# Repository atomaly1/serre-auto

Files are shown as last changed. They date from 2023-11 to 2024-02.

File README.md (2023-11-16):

# serre-auto
Projet de serre automatisée avec approche LowTech

## Commandes Git
### Première configuration
* git config --global user.name username
* git config --global user.email user@email.com

### Ajouter les changements
* git add .
* git commit -m "my commit message"
* git push origin dev-branch

### Pour créer une nouvelle branche
* git branch branchname
* git checkout branchname

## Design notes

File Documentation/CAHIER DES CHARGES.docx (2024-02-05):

# CAHIER DES CHARGES

PROJET 4 : INNOVATION ET RECHERCHE

THEME LOWTECH : SERRE AUTOMATISEE A LA FERME DES OURS DE BOOFZHEIM

Groupe projet

Mike AGNES | mike.agnes@insa-strasbourg.fr
Alban LOPEZ | alban.lopez@insa-strasbourg.fr
Lucie WABARTHA | lucie.wabartha@insa-strasbourg.fr

Tuteur

Marc VEDRINES | marc.vedrines@insa-strasbourg.fr

Client

Brice GAENG | fermedesours@gmail.com

# Révisions

Numéro | Commentaire - Modifications | Date
001 | Rédaction initiale | 11/10/2023
002 | Ajout du système de ventilation, encombrement dans la serre, symétrie des ouvrants latéraux, doublement des capteurs dans la serre | 12/10/2023
003 | Changement des températures limites des pièces | 12/10/2023

# 1 Exigences non-fonctionnelles

## 1.1 Exigences liées à la sécurité et à l’environnement de travail

### 1.1.1 Directives applicables

L’installation doit être conforme à la directive “machines” 2006/42/CE et aux autres directives applicables (Directive Basse Tension, ATEX, MID, PED...). Aucun élément dangereux en mouvement ne doit être accessible.

Le dossier technique doit comprendre les éléments suivants :

- Une description générale du système,
- Le plan d’ensemble de la machine, les plans des circuits de commande, ainsi que les descriptions et explications pertinentes nécessaires à la compréhension du fonctionnement de la machine,
- Les plans détaillé et complets, accompagnés des notes de calcul, résultats d’essais, attestations, etc.
- Les normes et autres spécifications techniques utilisées, en précisant les exigences essentielles de santé et de sécurité couvertes par ces normes,
- Une copie de la notice d’instructions du système ;

### 1.1.2 Sécurité

La sécurité de l’ensemble de l’installation doit être testée en validant les organes de sécurité (bouton d’arrêt d’urgence, barrière immatérielle, autre système mécanique, protection contre les rayonnements électromagnétiques ou laser, respect des exigences de sécurité intrinsèques Ex, pas de poussière ou corps inhalable).

### 1.1.3 Bruits

Le bruit environnant l’installation doit être inférieur ou égal à 70 dB. La documentation liée à la mesure des bruits émis par l’installation doit être fournie.

### 1.1.4 Environnement

Pensez à favoriser les fournisseurs locaux et les éléments recyclés pour le choix des matériaux lorsque cela est possible.

Anticipez l’élimination de l’équipement en fin de vie.

En cas d’émanation de gaz COV (Composé Organique Volatile) ou fumée une installation d’aspiration à la source doit être mise en place avec filtre.

### 1.1.5 Vibrations

Les niveaux de vibrations de l’installation ne doivent pas dépasser :

- 2,5 m/s ² pour les vibrations transmises aux mains et aux bras
- 0,5 m/s² pour les vibrations transmises à l’ensemble du corps

### 1.1.6 Charges

Si l’utilisation de l’installation nécessite la manipulation d’une charge, celle-ci doit être inférieur ou égale à 15 kg en translation et 10 kg en portage.

L’installation doit répondre aux exigences de la Norme NF X35-109 relative à l’Ergonomie - Manutention manuelle de charge pour soulever, déplacer et pousser/tirer - Méthodologie d’analyse et valeurs seuils.

### 1.1.7 Ergonomie

L’installation doit respecter le poids, la hauteur et la distance pour le stockage du matériel et pour le déplacement de charges mobiles (chariot...) selon les exigences de la Norme NX X35-109 relative à l’Ergonomie - Manutention manuelle de charge pour soulever, déplacer et pousser/tirer - Méthodologie d’analyse et valeurs seuils.

L’installation doit prendre en compte la diversité des tailles des collaborateurs conformément aux exigences de la Norme NF EN ISO 14738 relative aux Prescriptions anthropométriques relatives à la conception des postes de travail sur les machines.

L’installation doit respecter les limites de la force humaine pour son utilisation (presse, manivelle) en répondant aux exigences de la Norme NF EN 1005-3+A1 relative aux Limites des forces recommandées pour l’utilisation de machines.

### 1.1.8 Accessibilité

La réflexion sur l’équipement doit tenir compte de l’accessibilité et de la signalisation pour l’anticipation de la diversité des handicaps (vue, audition, sens cognitif, handicaps physiques ou autres).

## 1.2 Exigences liées aux produits chimiques utilisés pour le fonctionnement de l’installation

Les agents classés toxiques pour la reproduction de catégorie 1 ou 2 sont à proscrire :

- Benzène
- Dérivés suivants des hydrocarbures aromatiques
  - Dérivés suivants des hydrocarbures aromatiques
  - Dinitrophénol
  - Aniline et homologues, benzidine et homologues, naphtylamines et homologues

## 1.3 Exigences techniques standards

### 1.3.1 Protection ESD

L’installation doit être conforme aux exigences ESD (décharges électrostatiques). Les surfaces de travail non-métalliques doivent être conformes aux exigences antistatiques. Les pièces métalliques doivent être reliées à la terre.

### 1.3.2 Température des pièces

Les éléments externes de l’installation qui peuvent dépasser les 40°C doivent être identifiables. Les pièces de plus de 70°C devront impérativement être protégées par un dispositif adéquat.

### 1.3.3 Nettoyage

Les pièces qui nécessitent un nettoyage ne doivent pas dépasser les dimensions suivantes :
L x P x H : 750 x 600 x 600 mm

Ces pièces pourront être démontées rapidement et facilement sans outillage spécifique.

### 1.3.4 Mise en route de l’installation

L’installation doit pouvoir être opérationnelle 20 minutes maximum après la mise sous tension.

### 1.3.5 Dispositif d’urgence

L’installation doit comporter un dispositif d’arrêt d’urgence clairement identifié permettant d’arrêter immédiatement l’installation et de la mettre en sécurité en bloquant tous les éléments mobiles de l’installation. Le dispositif doit être accessible et à proximité de l’utilisateur, dans la zone de travail.

Le réarmement du bouton d’arrêt d’urgence ne doit pas provoquer un redémarrage de l’installation. Cependant l’installation doit pouvoir être redémarrée aisément sans une procédure spécifique de remise en état de marche.

### 1.3.6 Dispositifs de régulation

Un indicateur (affichage) de bon fonctionnement pour chaque dispositif de régulation doit être visible par l’utilisateur. Les valeurs seuils de ces indicateurs doivent être clairement affichées :

Vert = Dans la tolérance
Rouge = Hors tolérance supérieure
Jaune = Hors tolérance inférieure

### 1.3.7 Alimentation électrique

L’installation doit être optimisée énergétiquement. L’aspect énergétique sera l’un des critères majeurs de sélection des fournisseurs.

Si possible, un mode “économie d’énergie” ou une mise hors tension devra être prévu pour réduire l’impact énergétique de l’équipement lorsque celui-ci n’est pas en fonctionnement.

Pour chaque type d’énergie nécessaire au fonctionnement de l’installation, les valeurs suivantes doivent être communiquées :

- Consommation en veille en kWh
- Consommation nominale en kWh
- Consommation moyenne journalière en kWh

Tension de raccordement : Monophasé 230 VAC 50Hz

Régime de neutre : TT

### 1.3.8 Encombrement

Les dimensions maximales de l’installation ne doivent pas dépasser les dimensions suivantes :

- Largeur ou Longueur : 3 m
- Hauteur : 3 m

Dans les serres, en-dehors des parois, aucun équipement et aucun câble ne doit être positionné à moins de 2m de hauteur.

### 1.3.9 Poids

Le poids maximal de l’installation ne doit pas dépasser 2,5 T/m².

### 1.3.10 Disponibilité

L’installation doit être disponible 16h par jour (6h-22h). Une maintenance longue annuelle planifiée ne dépassant pas 3 jours maximum est tolérée.

La non-disponibilité journalière, en raison d’une intervention humaine pour maintenance préventive ou ajustage, ne doit pas dépasser 5% du temps d’utilisation.

### 1.3.11 Longévité

La conception de l’installation doit être prévue pour une durée de vie minimale de 10 ans.

## 1.4 Exigences liées à l’informatique et à la cybersécurité

### 1.4.1 Topologie réseau

L’installation doit pouvoir être connectée au réseau informatique via une prise Ethernet standardisée IEEE 802.3.

### 1.4.2 Système d’exploitation

Les systèmes d’exploitation Windows et Linux sont préconisés.

### 1.4.3 Applications

Les applications installées doivent être à jour de leur version la plus récente à la date de réception.

Si les applications sont concernées par les domaines ci-dessous elles doivent répondre aux prérequis indiqués.

A. Authentification
- Toute ressource qui n’est pas public doit faire l’objet d’un système d’authentification adapté au degré de confidentialité.
- La gestion des mots de passe dans l’interface utilisateurs ne doit pas permettre d’être visible d’un tiers ou de permettre l’auto-complétions.
- Les fenêtres d’authentification ne doivent être disponibles qu’en version crypté (url : https)
- Ne jamais fournir l’élément faux dans une connexion utilisateur / mot de passe erronée
- Si des mots de passe sont envoyé par mail non-crypté, ils doivent avoir une durée de validité limitée
- Ne jamais utiliser des mots de passe par défaut à la création d’un compte
- Les mots de passe ne doivent jamais transiter dans l’url en tant que paramètre
- Ne pas utiliser de système de récupération de mot de passe par question secrète
- Les mots de passe doivent respecter à minima les points suivants :
  - 12 caractères
  - Contenir chiffres
  - Contenir des lettres majuscules
  - Contenir des lettres minuscules
  - Contenir des caractères spéciaux
- Mettre en place des systèmes contre le “bruteforce” et l’attaques au dictionnaire lorsqu’il y a une fenêtre utilisateur / mot de passe
- Les informations de connexion ne devraient jamais être transmises ou stockées en clair
- Rediriger toutes les connexions http vers du https
- Toutes les connexions infructueuses doivent être logger
- Afficher la date de dernière connexion ainsi que le nombre d’erreur d’authentification commise
- Désactiver les comptes après plusieurs connexions infructueuses, attention tout de même aux DDOS
B. Gestion de session
- Les sessions doivent être révoquées après une période de temps
- Le serveur doit révoquer le session ID à la déconnexion
- Le stockage de la session doit se faire de manière sécurisée si elle contient des informations sensibles
- L’utilisateur doit avoir la possibilité de révoquer sa session manuellement
C. Autorisations
- Un contrôle d’autorisation doit être effectué si les ressources sont non-public et doit se faire du coté serveur et non du coté client
- Les utilisateurs ne doivent avoir que les droits nécessaires à leur besoin
- Mettre en place une page d’accès refusé pour les utilisateurs n’ayant pas de droits
D. Contrôle des saisies
- Toutes informations reçues par l’application doivent être vérifiées afin de garantir l’intégrité et la sécurité et ce du coté serveur
E. Encodage des données de contexte
- Tous les fichiers et données doivent fournir un encodage explicit, soit par le nom du fichier (css, js, etc.) soit par des mécaniques dans le code (Content-Type : text/html; charset=utf8, etc.).
F. Côté client
- Ne pas transmettre d’information confidentiel (mot de passe) du coté client
- Garantir la transmission sécurisée des données si nécessaire
G. Gestion de erreurs / Logs
- Ne pas mettre d’information confidentielle dans les messages d’erreurs

Le code source de l’application devra être fourni et documenté.

### 1.4.4 Ports USB

L’exécution automatique (Autorun) doit être désactivé sur tous les ports USB.

### 1.4.5 Antivirus

Le système doit être équipé d’un antivirus à jour.

### 1.4.6 Sauvegardes

Un système de sauvegarde des systèmes d’exploitation doit être fourni avec la solution.

## 1.5 Exigences liées à la documentation

L’installation doit être livrée avec une documentation complète, incluant, le manuel d’utilisation et la documentation technique.

Les inscriptions visibles sur l’installation et utilisables par les utilisateurs doivent être obligatoirement en français.

Liste des documents à fournir au plus tard pour la réception technique (ou pré-réception le cas échéant). Les documents devront idéalement être sous format informatique et les plans devront pouvoir être en version modifiable pour une éventuelle modification ultérieure.

Exigences concernées | Documents | Langue | Nombre exemplaires papier
Directive machine 2006/42/CE | Documentation technique de l’installation | Français | 1
Documentation | Manuel d’utilisation de l’installation | Français | 1
Documentation | Liste de tous les sous-traitants et fournisseurs pour chaque pièce et sous-ensemble | Français | 1
Maintenance | Liste des pièces critiques à mettre en stock | Français | 1
Maintenance | Liste des pièces d’usure | Français | 1
Maintenance | Manuel de maintenance préventive | Français | 1
Maintenance | Manuel de maintenance curative | Français | 1
Maintenance | Plan de maintenance standard pour l’utilisation spécifiée dans le cahier des charges | Français | 1
Informatique | Documentation du logiciel et code source des microcontrôleurs programmables | Français | 1

## 1.6 Exigences liées à la Maintenance

Une liste de toutes les pièces de rechange de l’équipement doit être fournie en spécifiant celles qui sont des pièces d’usure.

Une pièce d’usure est définie par les critères suivants :

- Mean Time Between Failure (MTBF) : < 30 000 heures

Une documentation technique complète de l’installation doit être fournie comprenant à minima les schémas électriques, mécaniques, pneumatiques et hydrauliques ainsi qu’un manuel de maintenance.

Un plan de maintenance préventive standard pour l’utilisation spécifiée doit être fourni (il peut être intégré au manuel de maintenance).

## 1.7 Confidentialité

Le fournisseur s’engage à mettre à disposition du grand public l’ensemble de la documentation de l’installation. Ceci a pour but d’encourager la reproduction et l’amélioration du système développé.

## 1.8 Transport et livraison

L’installation devra être livrée à l’adresse suivante :

Ferme des Ours
rue de Strasbourg
67860 Boofzheim (France)

Le transport de la marchandise jusqu’à l’adresse de livraison, l’installation de l’équipement à son emplacement définitif et sa mise en service sont sous la responsabilité du fournisseur.

## 1.9 Formation

La formation des utilisateurs experts est sous la responsabilité du fournisseur.

La formation des utilisateurs devra aborder les thèmes suivants (liste non-exhaustive) :

- Connaissances techniques matériel/logiciel
- Contenu du manuel utilisateur
- Description des différents signaux (lumineux, sonore, etc.)
- Contenu des opérations de maintenance
- Formation minimum à l’utilisation

# 1 Exigences fonctionnelles

## 1.1 Présentation générale

### 1.1.1 Fondement du projet

Ce projet s’inscrit dans le cursus d’étude d’ingénieur en mécatronique par alternance de l’INSA Strasbourg et plus spécifiquement dans le module Projet 4 : Recherche et Innovation. La thématique générale abordée est la LowTech avec comme axe pratique l’automatisation d’une serre maraîchère.

Le projet est réalisé conjointement par trois étudiants de l’INSA, un professeur référent ainsi qu’un maraîcher de la région Strasbourgeoise.

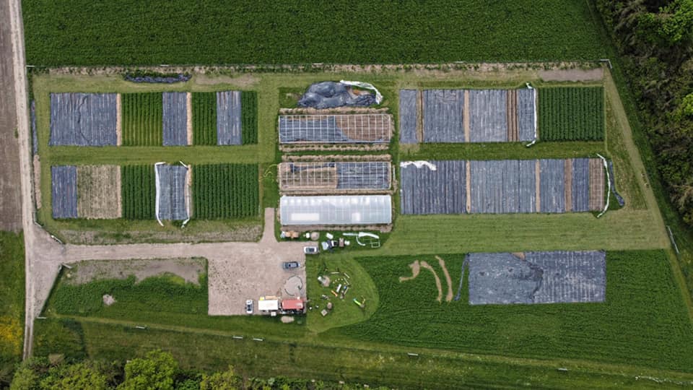
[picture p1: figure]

Figure 1: Vue aérienne de la Ferme des Ours à Boofzheim (67)

L’objectif principal est de réaliser une régulation de la température et de l’humidité d’une serre, par l’automatisation des ouvrants latéraux.

### 1.1.2 Attentes du projet

A. Procédé

Motorisation et automatisation des ouvrants d'une serre ainsi qu'automatisation d'un ventilateur. Le but est de réguler la température intérieure, l'humidité et de protéger la serre en cas d'orages. Le système doit intégrer des capteurs de températures, d'humidité et de niveau de vent. Il doit être possible pour l'utilisateur de définir ses propres seuils, et de passer en mode manuel en cas de besoin. L'utilisateur doit pouvoir visualiser les caractéristiques des capteurs et accéder à l'historique des données.

B. Documentation

Le projet est réalisé en accord avec les valeurs de libre échange des informations et des données. Toutes les informations nécessaires à la reproduction et à la modification du système seront mises à disposition du grand public.

### 1.1.3 Planification

La planification du projet s’oriente en quatre phases principales. Ces phases sont détaillées dans le tableau ci-dessous.

Tableau 1 : Planification du projet de serre automatisée

| Phases | Planifié pour
1 | Rédactions de veilles technologiques | 13/10/23
| Analyse de l'existant | 13/10/23
| Rédaction cahier des charges | 13/10/23
2 | Choix des solutions électronique | 15/11/23
| Choix des solutions mécanique | 15/11/23
| Ecriture du programme | 15/11/23
3 | Mise en place d'une liste de tests | 16/12/23
4 | Création de la documentation, rapport et support de présentation | 11/01/24

## 1.2 Description de l’état actuel

### 1.2.1 Topographie

Le terrain dispose d’une superficie totale de 0,89 hectare. Il est situé à l'abord de la rue de Strasbourg à l’entrée du village de Boofzheim (67860).

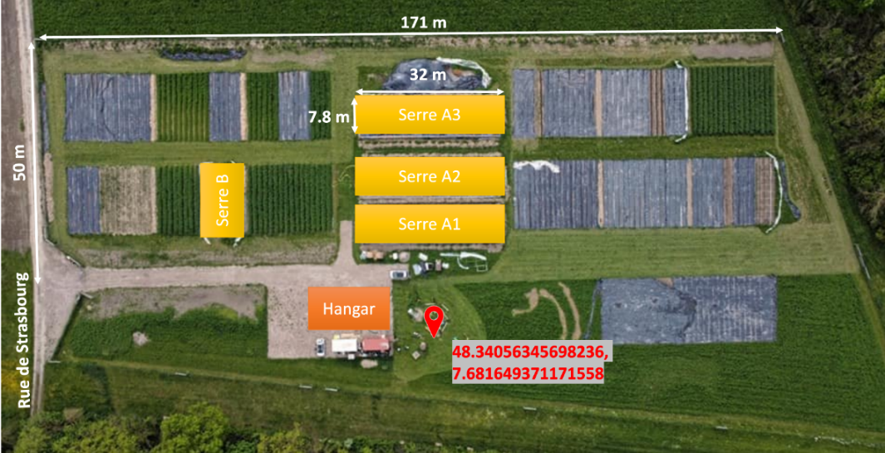
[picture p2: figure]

Figure 2 : Topographie du site de la Ferme des Ours

La serre est un produit standard “TUNNEL Pro 7.80M SC” fournie par Serresvaldeloire dont le plan est illustré ci-dessous.

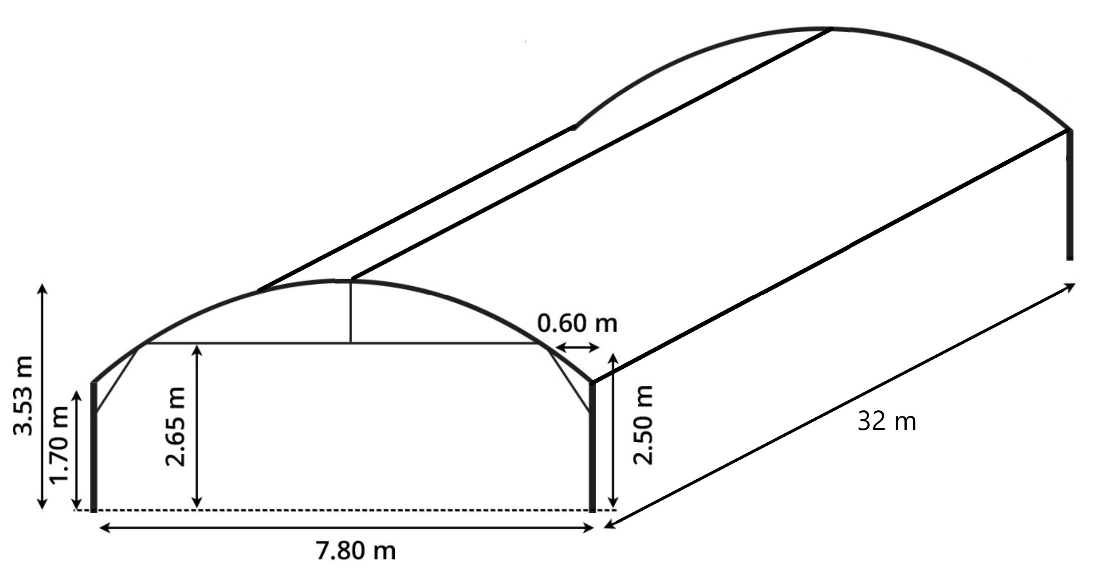
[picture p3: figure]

Figure 3 : Dimensions de la serre TUNNEL Pro 7.80M SC

### 1.2.2 Système mécanique d’ouverture

Le système actuel permettant l’ouverture des ouvrants latéraux se compose d’une manivelle entraînant un réducteur. Un bras télescopique en rotation permet la transmission au tube provoquant l’enroulage ou le déroulage de la bâche couvrant les ouvrants.

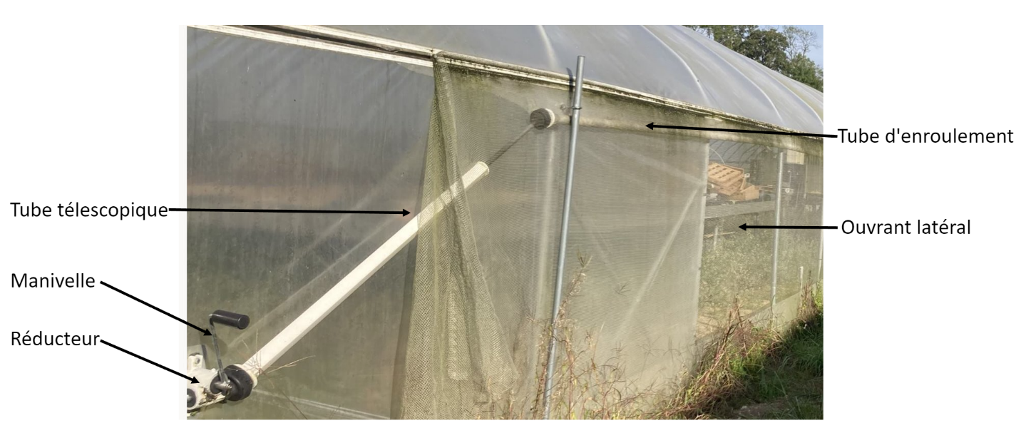
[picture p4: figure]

Figure 4 : Nomenclature du système d'ouverture latéral

### 1.2.3 Procédé

Lorsque l’utilisateur juge que la température ou l’humidité dans la serre est trop importante, il actionne, une après l’autre, les deux manivelles pour enrouler les bâches latérales.

Dans une logique similaire, lorsque l’utilisateur juge le temps défavorable, il actionne les manivelles de manière à descendre les bâches latérales.

### 1.2.4 Réseau

Le hangar dispose d’un routeur Wi-Fi 5 GHz / 2,4 GHz qui recouvre l’entièreté du terrain. Le réseau Wi-Fi n’est pas relié au réseau internet.

### 1.2.5 Alimentation

Le hangar dispose d’un coffret électrique relié au réseau EDF (230 VAC 50Hz). Chaque serre contient un coffret électrique déporté du coffret principal.

## 1.3 Description du procédé souhaité

### 1.3.1 Fonctions principales

A. Ouvrir et fermer automatiquement la serre en fonction des conditions fixées par l'utilisateur

Le système, en mode automatique, doit gérer la température et l’humidité interne de la serre, en actionnant automatiquement l’ouverture et la fermeture des ouvrants afin de ne pas dépasser les seuils renseignés par l’utilisateur. De plus, un système de ventilation peut être activé automatiquement.

Par ailleurs, le système doit automatiquement fermer les ouvrants en cas de vent trop violent afin de protéger la serre.

B. Permettre à l'utilisateur d'actionner la motorisation de l'ouverture et la fermeture de la serre

Lorsqu’il le souhaite, l’utilisateur doit pouvoir ouvrir et fermer les ouvrants par le biais d’une commande électrique physique prioritaire par rapport à l’asservissement.

C. Permettre à l'utilisateur d'effectuer manuellement l'ouverture et la fermeture de la serre

Lorsque le système n’est pas alimenté électriquement, l’utilisateur doit pouvoir actionner un système mécanique permettant d’ouvrir et de fermer les ouvrants latéraux de la serre.

D. Permettre à l’utilisateur d’actionner le système de ventilation

Lorsqu’il le souhaite, l’utilisateur doit pouvoir allumer et éteindre le système de ventilation par le biais d’une commande électrique physique prioritaire par rapport à l’asservissement.

### 1.3.2 Fonctions contraintes

A. Permettre une ouverture variable et symétrique des parois latérales

Le taux d’ouverture des parois latérales peut être situé entre une valeur maximale (serre complètement ouverte) et minimale (serre complètement fermée). Les deux ouvrants sont contrôlés par la même loi de commande et sont donc actionnés conjointement.

B. Informer l'utilisateur des paramètres de régulation via une interface numérique locale

Une interface permettant un affichage des données de la serre et des seuils doit être intégrée au système et consultable sur le réseau local de l’utilisateur.

C. Permettre à l'utilisateur de paramétrer les valeurs de seuils

Les seuils de tolérance des différentes données (température, humidité et intensité du vent) gérées par le système, doivent être paramétrables via une interface par l’utilisateur.

D. Permettre à l'utilisateur de visualiser l'historiques des données mesurées

Un suivi des données de température, d’humidité et d’intensité de vent doit être possible. Pour se faire, les données récoltées par les capteurs doivent être stockées et consultable par l’utilisateur.

E. Alimenter électriquement le système

Le système doit être alimenté électriquement par le biais de l’arrivée électrique du client (réseau EDF). Un coffret électrique est disposé dans chaque serre.

F. Exploiter uniquement de l'énergie électrique et mécanique

Seules les sources d’énergie déjà présentes sur site seront utilisées. Aucun autre système pneumatique, hydraulique ou thermique ne sera mis en place.

G. Résister aux conditions climatiques

Conditions limites à l’intérieur de la serre :

- Température : -10°C à 70°C
- Humidité (degré hygrométrique) : 10% à 100%
- Vitesse de vent : Faible

Conditions limites à l’extérieure de la serre :

- Température : -25°C à 50°C
- Humidité (degré hygrométrique) : 10% à 100%
- Vitesse de vent : Rafales pouvant aller jusqu’à 150 km/h
H. Utiliser du matériel et des technologies standardisés

Le système doit être constitué de composants facilement remplaçables et produit en grandes séries. Les technologies mises en œuvre doivent également être répandues et les ressources nécessaires à la formation à ces équipements doivent être disponibles en ligne et gratuitement.

I. Utiliser des logiciels libres

Privilégier l’utilisation de logiciels et systèmes d’exploitation libres (aussi connu sous l’appellation open source) et gratuits.

J. Réduire/optimiser la consommation énergétique du système

Les choix de composants, de stratégies à appliquer et de matériaux doivent être réalisés en tenant compte de la consommation énergétique générée, afin de réduire au mieux la dépense énergétique du système.

K. Garantir l’intégrité et la qualité des données

Si possible, les capteurs situés dans la serre devront être doublés afin de garantir l’intégrité et la qualité des valeurs mesurées.

# Annexe

## A. Documentation du réducteur

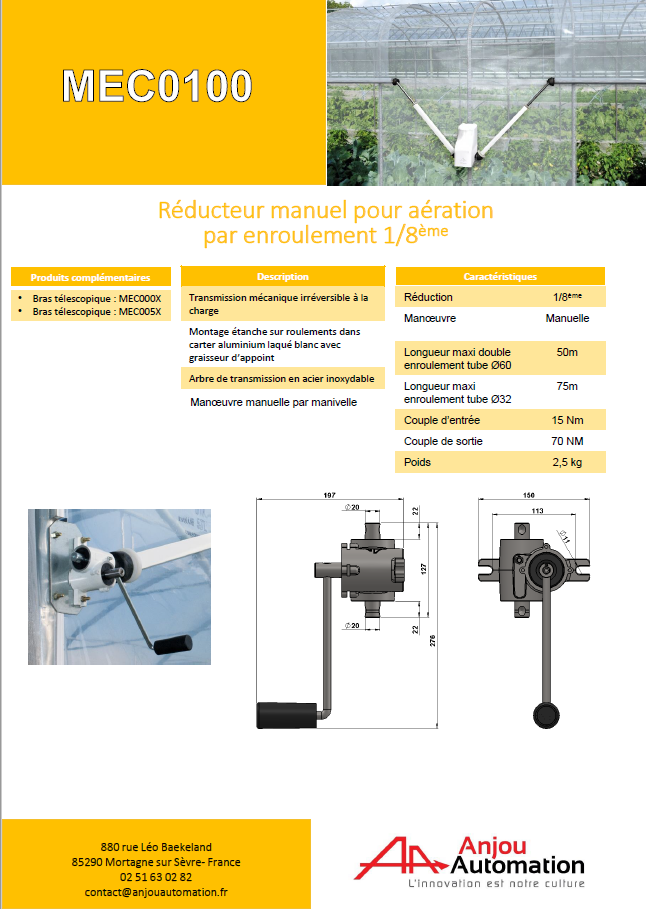
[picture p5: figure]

## B. Documentation du bras télescopique

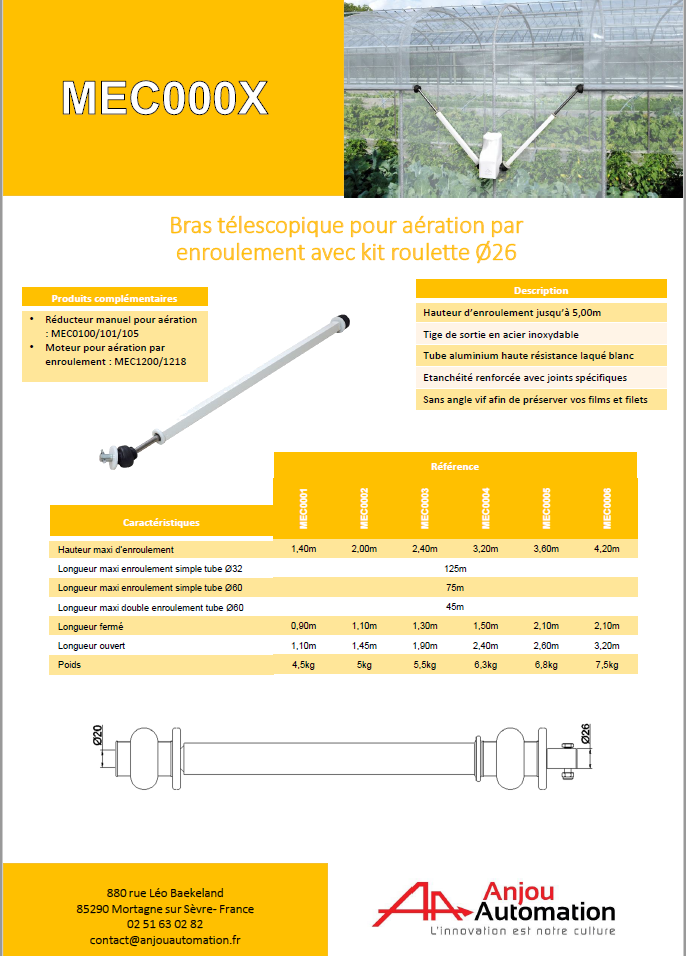
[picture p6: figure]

Département de Génie Mécanique & Mécatronique

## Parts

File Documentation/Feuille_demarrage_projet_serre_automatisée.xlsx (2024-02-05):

Feuille de Démarrage de projet
Nom du projet: |  | Serre Automatisée Lowtech : Ferme des Ours à Boofzheim
1 - VUE D'ENSEMBLE (Description de l'état actuel / Problème) |  |  |  |  |  |  | 2 - ATTENTES DU PROJET (Description de l'état souhaité) |  | 18
Etat actuel Ouverture/Fermeture de la serre à l'aide d'une manivelle. Absence de capteurs de température, de taux d'humidité et de vitesse de vent. Le client ouvre et ferme la serre à la main. Cela est fait en fonction de la météo qui parfois varie rapidement dans une journée. Problème Lorsque la serre est exposée au soleil, la température monte très rapidement. Si la serre n'est pas ouverte, l'ensemble des cultures peuvent être perdues en quelques heures. Cela représente une perte de temps et de qualité de vie pour le maraîcher. Il y a également un risque de dégradation de la serre en cas d'orage ou de vents forts. |  |  |  |  |  |  | Process Motorisation et automatisation des ouvrants d'une serre ansi que automatisation d'un ventilateur. Le but est de réguler la température intérieure, l'humidité et de protéger la serre en cas d'orages. Le système doit intégrer des capteurs de températures, d'humidité et de niveau de vent. Il doit être possible pour l'utilisateur de définir ses propres seuils, et de passer en mode manuel en cas de besoin. L'utilisateur doit pouvoir visualiser les caractéristiques des capteurs et accéder à l'historique des données.
 |  |  |  |  |  |  | Limites du projet
 |  |  |  |  |  |  | Non abordé dans ce projet Le projet s'arrête aux ouvertures latérales de la serre, ainsi que, si le temps le permet, de l'automatisation d'un système de ventilation. L'irrigation de la serre, l'ensoleillement, le taux de CO2 ainsi que l'orientation du vent ne seront notamment pas étudiés.
 |  |  |  |  |  |  | Livrables du projet (hors produit)
 |  |  |  |  |  |  | Une documentation claire expliquant le fonctionnement du système et comment le modifier/réparer (schémas éléctriques et mécaniques, programmes commentés, instructions...).
5 - PLANNING |  |  |  |  |  |  | 6 - EQUIPE
 | Phases |  |  | Planifié pour |  | Réalisé | Nom | Fonction
1 | Rédactions de veilles techno (meca/électronique) |  |  | 13/10/23 |  |  | AGNES Mike | Apprenti Ingénieur mécatronicien
 | Analyse de l'existant |  |  | 13/10/23 |  |  | LOPEZ Alban | Apprenti Ingénieur mécatronicien
 | Rédaction cahier des charges |  |  | 13/10/23 |  |  | WABARTHA Lucie | Apprentie Ingénieure mécatronicienne
2 | Choix des solutions (électronique) |  |  | 15/11/23 |  |  | VEDRINES Marc | Tuteur de projet - Professeur mécanique
 | Choix des solutions (mécanique) |  |  | 15/11/23 |  |  | GAENG Brice | Client - Maraîcher
 | Ecriture du programme |  |  | 15/11/23
3 | Mise en place d'une liste de tests |  |  | 16/12/23
4 | Création de la documentation, rapport et support de présentation |  |  | 11/01/24
Projet validé par (Date, Signature)
Tuteur du projet |  |  | Equipe projet |  | Client

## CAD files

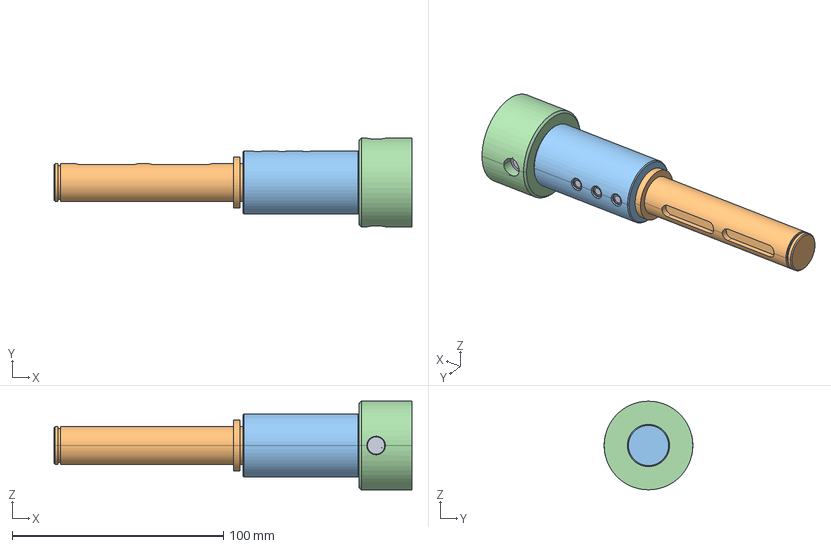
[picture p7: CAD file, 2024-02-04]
Documentation/CAO/Accouplement moteur - bras télescopique/STEP/a1-accouplement_moteur_1_asm.stp
169.5 x 42.0 x 42.0 mm
100-TECHNOI_425001_ARBRE_SORTIE
10-ACCOUPLEMENT
200-ANJOU_MEC0002_BRAS_TELESCOP
300-BOSSARD_BN617_VIS_M6X8 x 3
310-BOSSARD_BN617_VIS_M10X12 x 2

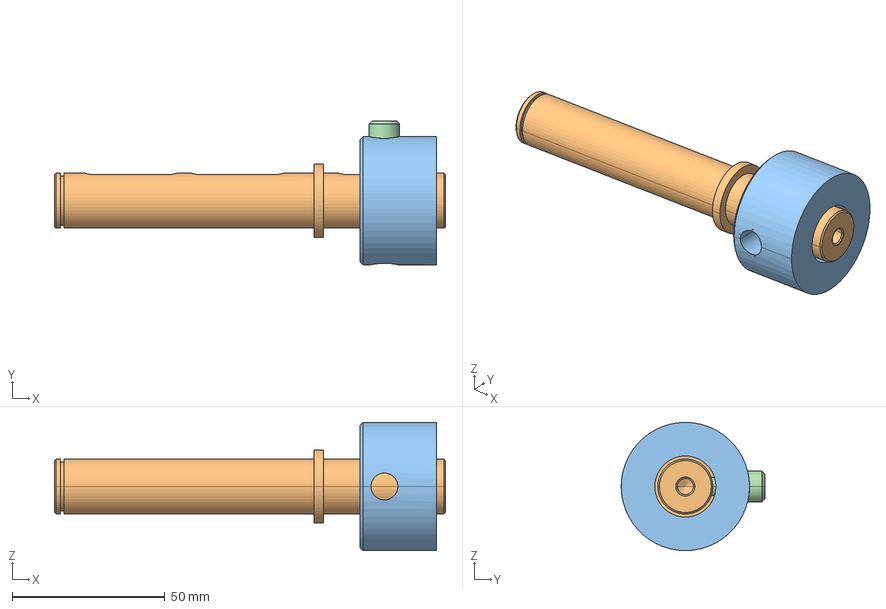
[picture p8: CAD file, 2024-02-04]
Documentation/CAO/Accouplement moteur - bras télescopique/STEP/a2-accouplement_moteur_2_asm.stp
128.0 x 47.0 x 42.0 mm
100-TECHNOI_425001_ARBRE_SORTIE
200-ANJOU_MEC0002_BRAS_TELESCOP
320-BOSSARD_BN619_VIS_M10X20_L

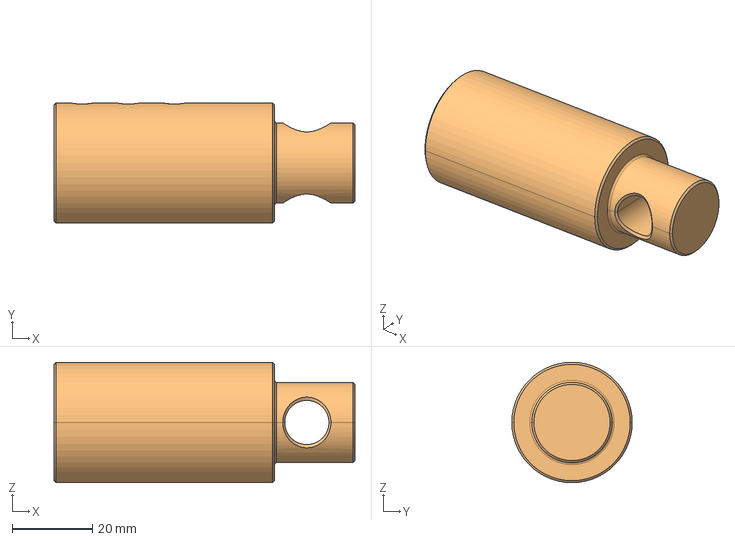
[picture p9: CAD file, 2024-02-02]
Documentation/CAO/accouplement.stp
75.0 x 30.0 x 30.0 mm

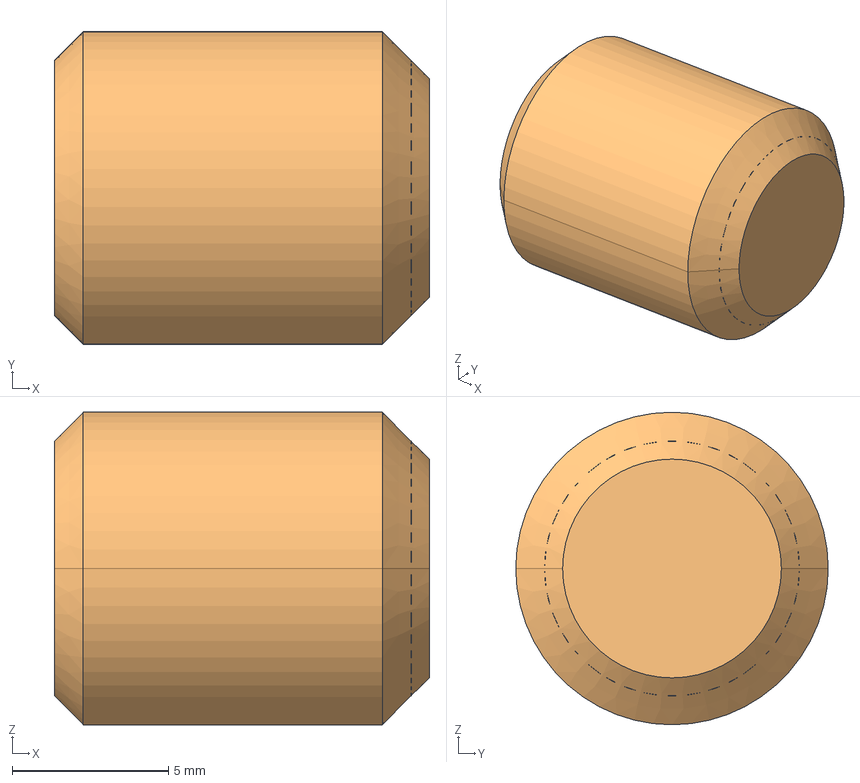
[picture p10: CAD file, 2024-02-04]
Documentation/CAO/Accouplement moteur - bras télescopique/STEP/310-bossard_bn617_vis_m10x12.stp
12.0 x 10.0 x 10.0 mm

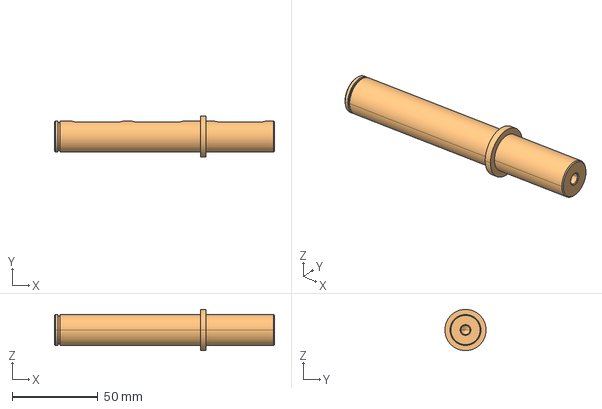
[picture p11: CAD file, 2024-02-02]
Documentation/CAO/arbre_reducteur.stp
128.0 x 24.0 x 24.0 mm

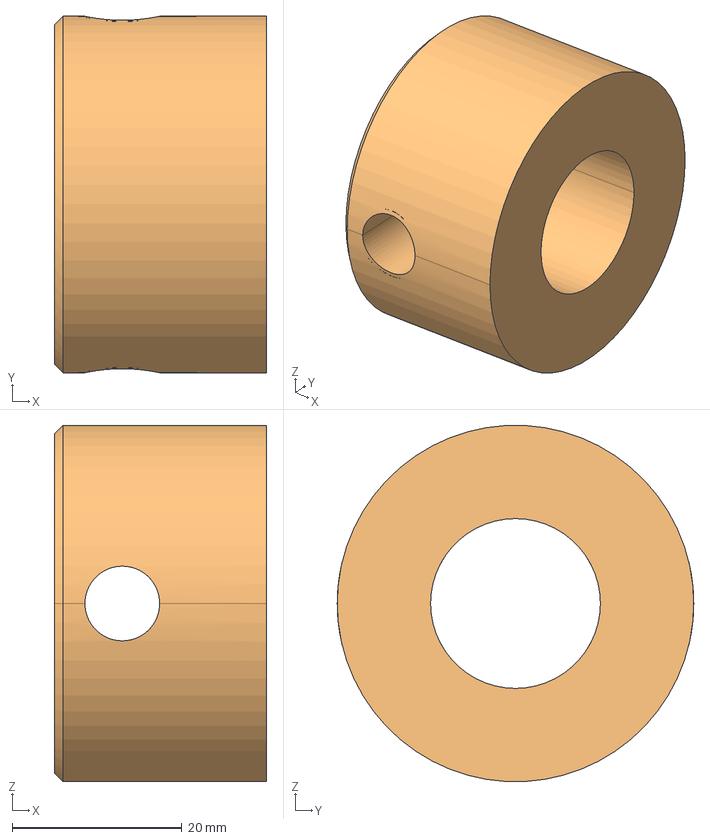
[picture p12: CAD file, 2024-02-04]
Documentation/CAO/Accouplement moteur - bras télescopique/STEP/200-anjou_mec0002_bras_telescop.stp
25.0 x 42.0 x 41.9 mm

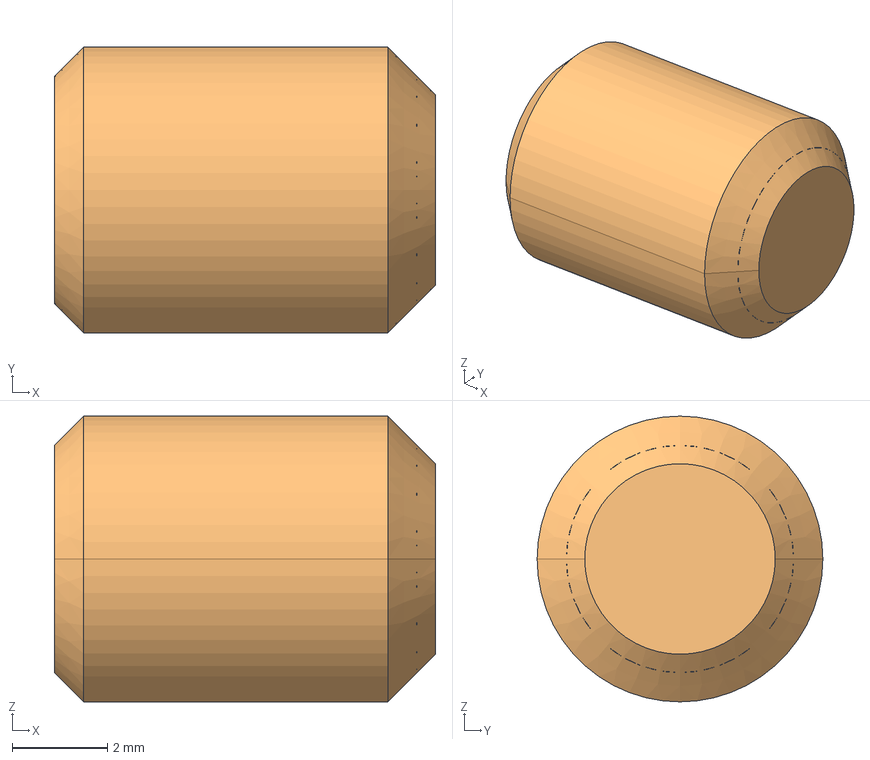
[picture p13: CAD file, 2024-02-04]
Documentation/CAO/Accouplement moteur - bras télescopique/STEP/300-bossard_bn617_vis_m6x8.stp
8.00 x 6.00 x 6.00 mm

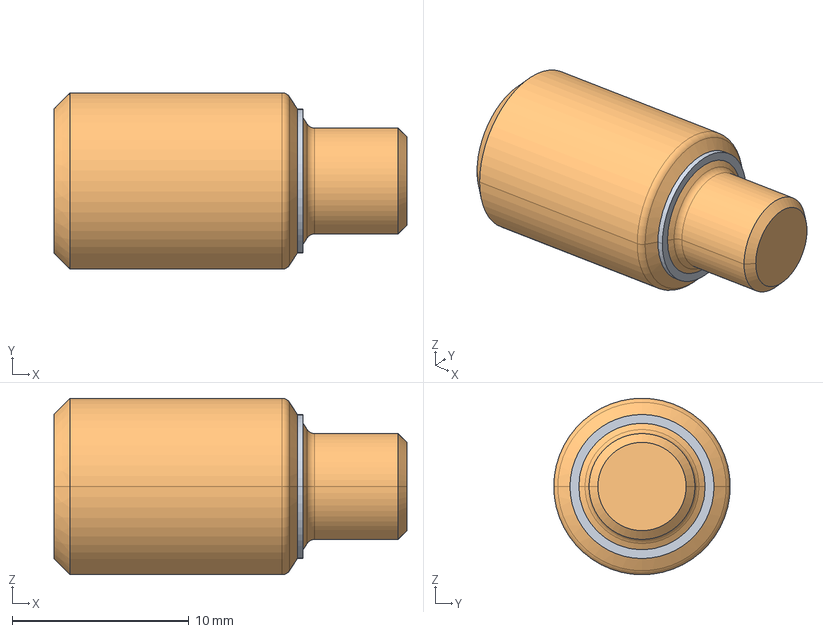
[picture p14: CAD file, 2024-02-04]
Documentation/CAO/Accouplement moteur - bras télescopique/STEP/320-bossard_bn619_vis_m10x20_l.stp
20.0 x 10.0 x 10.0 mm

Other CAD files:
Documentation/CAO/Accouplement moteur - bras télescopique/DXF/a1-accouplement_moteur_1.dxf
Documentation/CAO/Accouplement moteur - bras télescopique/DXF/a2-accouplement_moteur_2.dxf
Documentation/CAO/entree_bras_telesc.stp
Documentation/CAO/Accouplement moteur - bras télescopique/STEP/100-technoi_425001_arbre_sortie.stp
Documentation/CAO/Accouplement moteur - bras télescopique/STEP/10-accouplement.stp
Documentation/CAO/Accouplement moteur - bras télescopique/10-accouplement.prt
Documentation/CAO/Accouplement moteur - bras télescopique/100-technoi_425001_arbre_sortie.prt
Documentation/CAO/Accouplement moteur - bras télescopique/200-anjou_mec0002_bras_telescop.prt
Documentation/CAO/Accouplement moteur - bras télescopique/300-BOSSARD_BN617_vis_M6x8.prt
Documentation/CAO/Accouplement moteur - bras télescopique/310-BOSSARD_BN617_vis_M10x12.prt
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

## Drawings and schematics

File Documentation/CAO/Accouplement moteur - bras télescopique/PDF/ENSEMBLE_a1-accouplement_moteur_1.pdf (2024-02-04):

# COUPE A-A

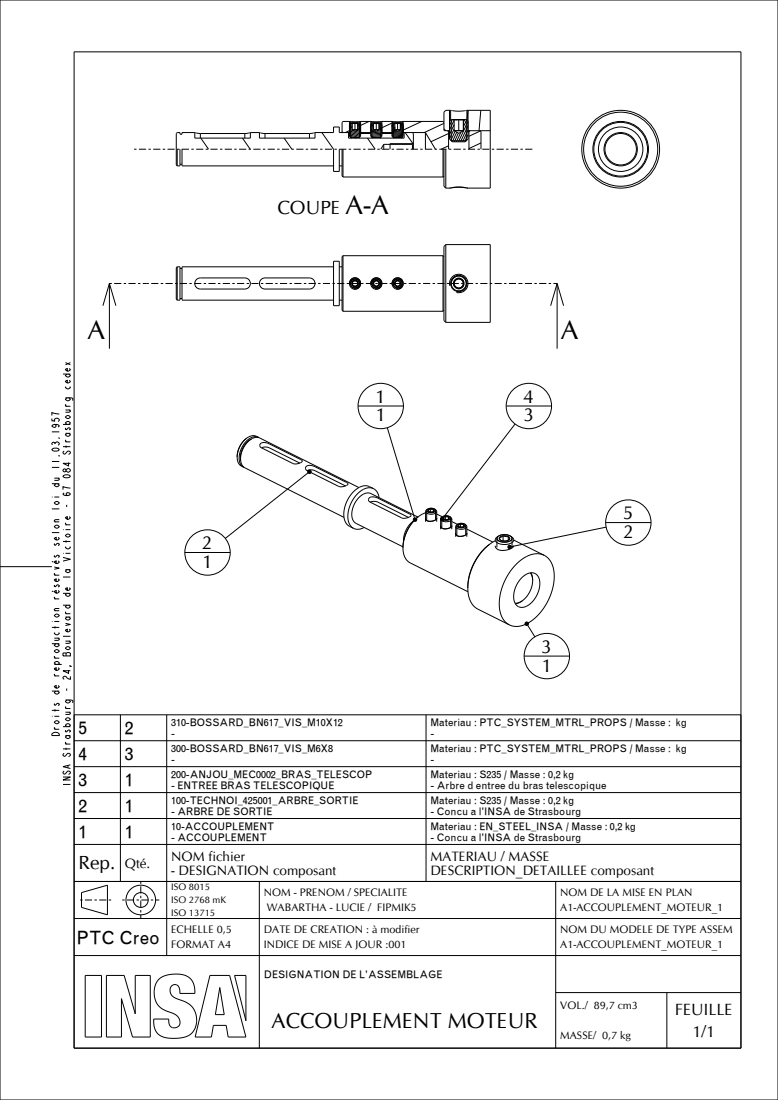
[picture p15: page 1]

INSA Strasbourg - 24, Boulevard de la Victoire - 67 084 Strasbourg cedex

Droits de reproduction réservés selon loi du 11.03.1957

5 | 2 | 310-BOSSARD_BN617_VIS_M10X12 - | Materiau : PTC_SYSTEM_MTRL_PROPS / Masse : kg -

4 | 3 | 300-BOSSARD_BN617_VIS_M6X8 - | Materiau : PTC_SYSTEM_MTRL_PROPS / Masse : kg -

3 | 1 | 200-ANJOU_MEC0002_BRAS_TELESCOP - ENTREE BRAS TELESCOPIQUE | Materiau : S235 / Masse : 0,2 kg - Arbre d entree du bras telescopique

2 | 1 | 100-TECHNOI_425001_ARBRE_SORTIE - ARBRE DE SORTIE | Materiau : S235 / Masse : 0,2 kg - Concu a l'INSA de Strasbourg

1 | 1 | 10-ACCOUPLEMENT - ACCOUPLEMENT | Materiau : EN_STEEL_INSA / Masse : 0,2 kg - Concu a l'INSA de Strasbourg
Rep. | Qté. | NOM fichier - DESIGNATION composant | MATERIAU / MASSE DESCRIPTION_DETAILLEE composant

ISO 8015 ISO 2768 mK ISO 13715 | NOM - PRENOM / SPECIALITE WABARTHA - LUCIE / FIPMIK5 | NOM DE LA MISE EN PLAN A1-ACCOUPLEMENT_MOTEUR_1

PTC Creo | | | | ECHELLE 0,5 FORMAT A4 | DATE DE CREATION : à modifier INDICE DE MISE A JOUR :001 | NOM DU MODELE DE TYPE ASSEM A1-ACCOUPLEMENT_MOTEUR_1

DESIGNATION DE L'ASSEMBLAGE ACCOUPLEMENT MOTEUR

VOL./ 89,7 cm3 MASSE/ 0,7 kg | FEUILLE 1/1

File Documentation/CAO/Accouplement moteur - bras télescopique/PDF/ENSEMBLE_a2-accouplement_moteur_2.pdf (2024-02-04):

# COUPE A-A

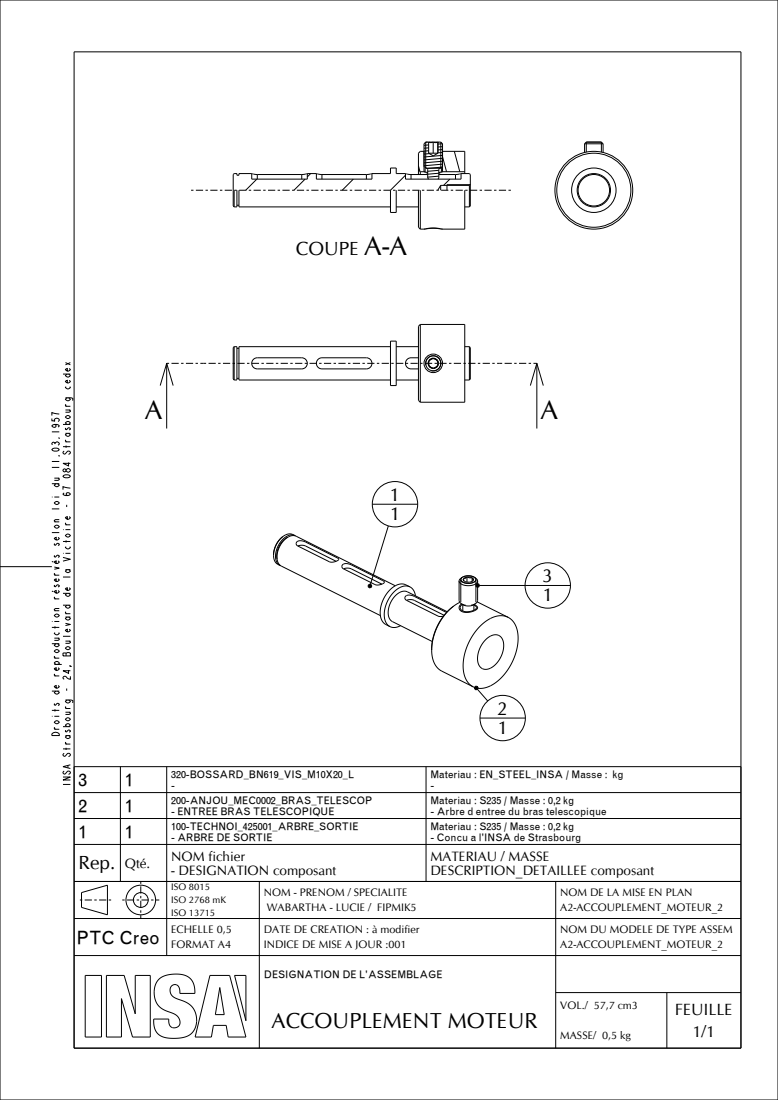
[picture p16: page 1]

INSA Strasbourg - 24, Boulevard de la Victoire - 67 084 Strasbourg cedex

Droits de reproduction réservés selon loi du 11.03.1957

3 | 1 | 320-BOSSARD_BN619_VIS_M10X20_L - | Materiau : EN_STEEL_INSA / Masse : kg -

2 | 1 | 200-ANJOU_MEC0002_BRAS_TELESCOP - ENTREE BRAS TELESCOPIQUE | Materiau : S235 / Masse : 0,2 kg - Arbre d entree du bras telescopique

1 | 1 | 100-TECHNOI_425001_ARBRE_SORTIE - ARBRE DE SORTIE | Materiau : S235 / Masse : 0,2 kg - Concu a l'INSA de Strasbourg
Rep. | Qté. | NOM fichier - DESIGNATION composant | MATERIAU / MASSE DESCRIPTION_DETAILLEE composant

ISO 8015 ISO 2768 mK ISO 13715 | NOM - PRENOM / SPECIALITE WABARTHA - LUCIE / FIPMIK5 | NOM DE LA MISE EN PLAN A2-ACCOUPLEMENT_MOTEUR_2

PTC Creo | | | | ECHELLE 0,5 FORMAT A4 | DATE DE CREATION : à modifier INDICE DE MISE A JOUR :001 | NOM DU MODELE DE TYPE ASSEM A2-ACCOUPLEMENT_MOTEUR_2

DESIGNATION DE L'ASSEMBLAGE ACCOUPLEMENT MOTEUR

VOL./ 57,7 cm3 MASSE/ 0,5 kg | FEUILLE 1/1

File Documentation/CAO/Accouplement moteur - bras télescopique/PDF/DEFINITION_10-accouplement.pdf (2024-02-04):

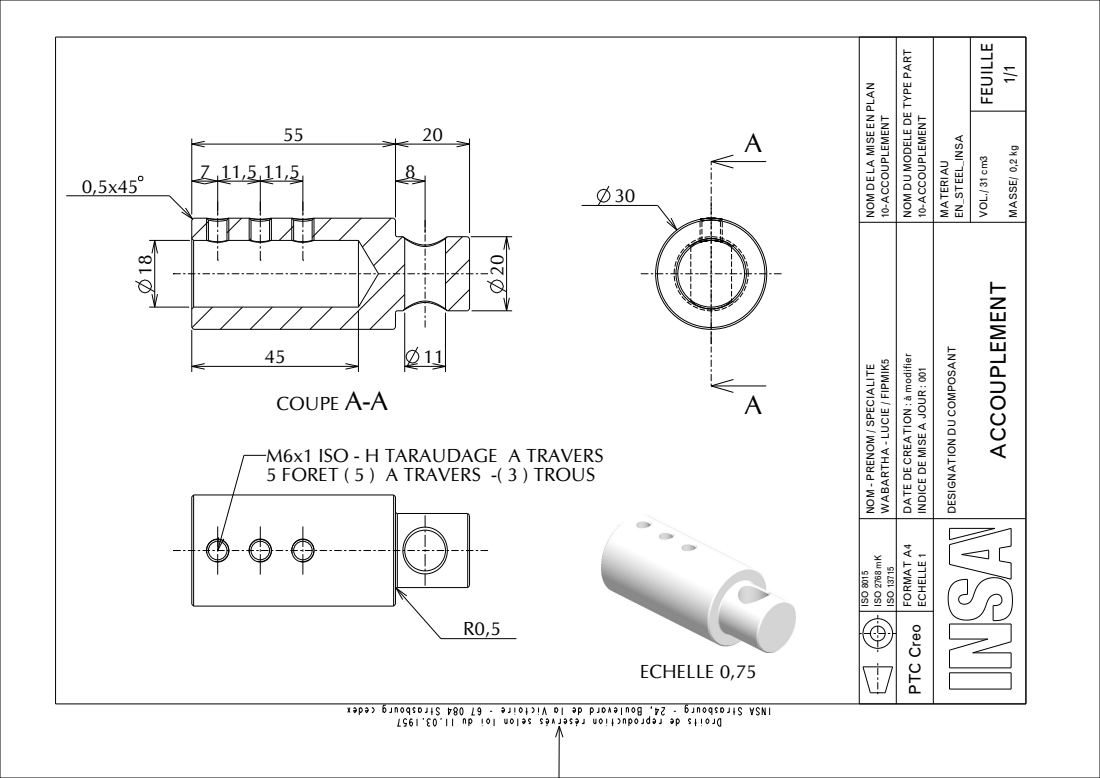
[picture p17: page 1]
ISO 8015; ISO 2768 mK; ISO 13715; WABARTHA - LUCIE / FIPMIK5; 10-ACCOUPLEMENT; ACCOUPLEMENT; VOL./ 31 cm3; MASSE/ 0,2 kg; FEUILLE; COUPE A-A; ECHELLE 0,75

PTC Creo FORMAT A4 ECHELLE 1 DATE DE CREATION : à modifier INDICE DE MISE A JOUR : 001 NOM DU MODELE DE TYPE PART 10-ACCOUPLEMENT

NOM DE LA MISE EN PLAN

DESIGNATION DU COMPOSANT MATERIAU EN_STEEL_INSA

NOM - PRENOM / SPECIALITE

M6x1 ISO - H TARAUDAGE A TRAVERS
5 FORET ( 5 ) A TRAVERS -( 3 ) TROUS

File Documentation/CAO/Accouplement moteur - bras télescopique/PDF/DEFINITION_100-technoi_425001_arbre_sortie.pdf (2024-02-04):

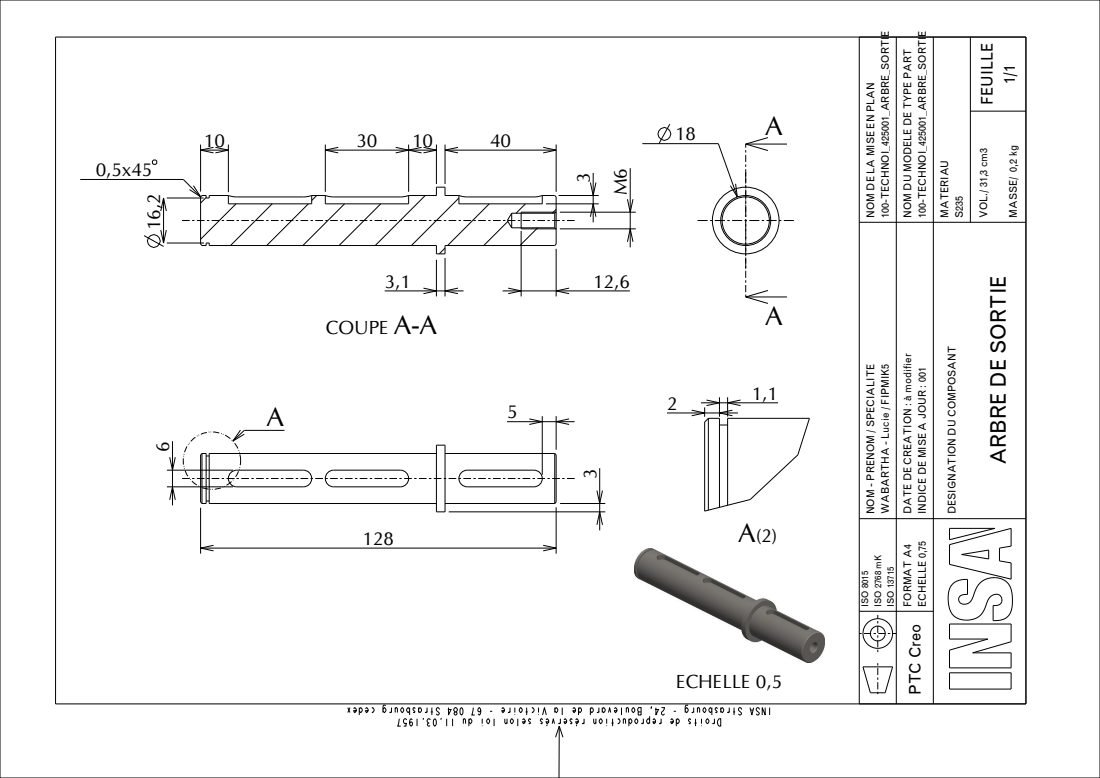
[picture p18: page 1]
ISO 8015; ISO 2768 mK; ISO 13715; WABARTHA - Lucie / FIPMIK5; 100-TECHNOI_425001_ARBRE_SORTIE; VOL./ 31,3 cm3; MASSE/ 0,2 kg; FEUILLE; COUPE A-A; ECHELLE 0,5

PTC Creo FORMAT A4 ECHELLE 0,75 DATE DE CREATION : à modifier INDICE DE MISE A JOUR : 001 NOM DU MODELE DE TYPE PART 100-TECHNOI_425001_ARBRE_SORTIE

NOM DE LA MISE EN PLAN

DESIGNATION DU COMPOSANT MATERIAU S235

ARBRE DE SORTIE

NOM - PRENOM / SPECIALITE

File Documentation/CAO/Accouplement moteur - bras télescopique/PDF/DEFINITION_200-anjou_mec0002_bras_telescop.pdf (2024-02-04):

42
1x45

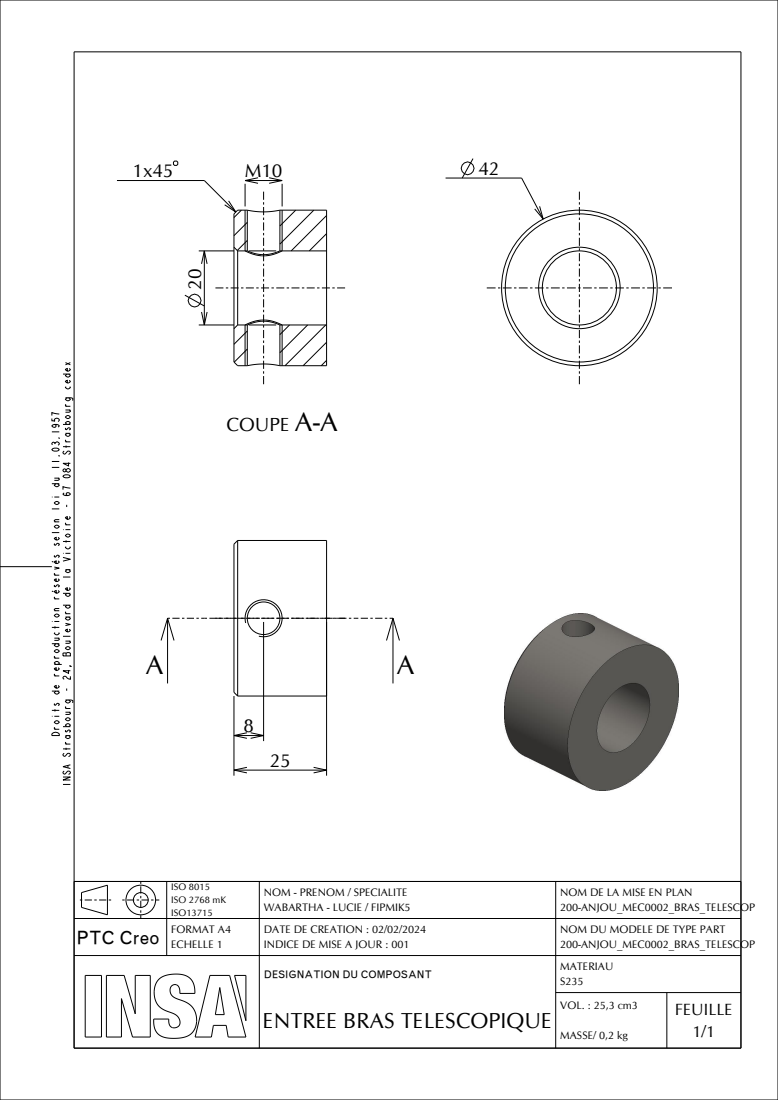
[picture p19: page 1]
COUPE A-A

INSA Strasbourg - 24, Boulevard de la Victoire - 67 084 Strasbourg cedex

Droits de reproduction réservés selon loi du 11.03.1957

ISO 8015 ISO 2768 mK ISO13715 | NOM - PRENOM / SPECIALITE WABARTHA - LUCIE / FIPMIK5 | NOM DE LA MISE EN PLAN 200-ANJOU_MEC0002_BRAS_TELESCOP

PTC Creo | | FORMAT A4 ECHELLE 1 | DATE DE CREATION : 02/02/2024 INDICE DE MISE A JOUR : 001 | NOM DU MODELE DE TYPE PART 200-ANJOU_MEC0002_BRAS_TELESCOP

DESIGNATION DU COMPOSANT ENTREE BRAS TELESCOPIQUE | MATERIAU S235

VOL. : 25,3 cm3 MASSE/ 0,2 kg | FEUILLE 1/1

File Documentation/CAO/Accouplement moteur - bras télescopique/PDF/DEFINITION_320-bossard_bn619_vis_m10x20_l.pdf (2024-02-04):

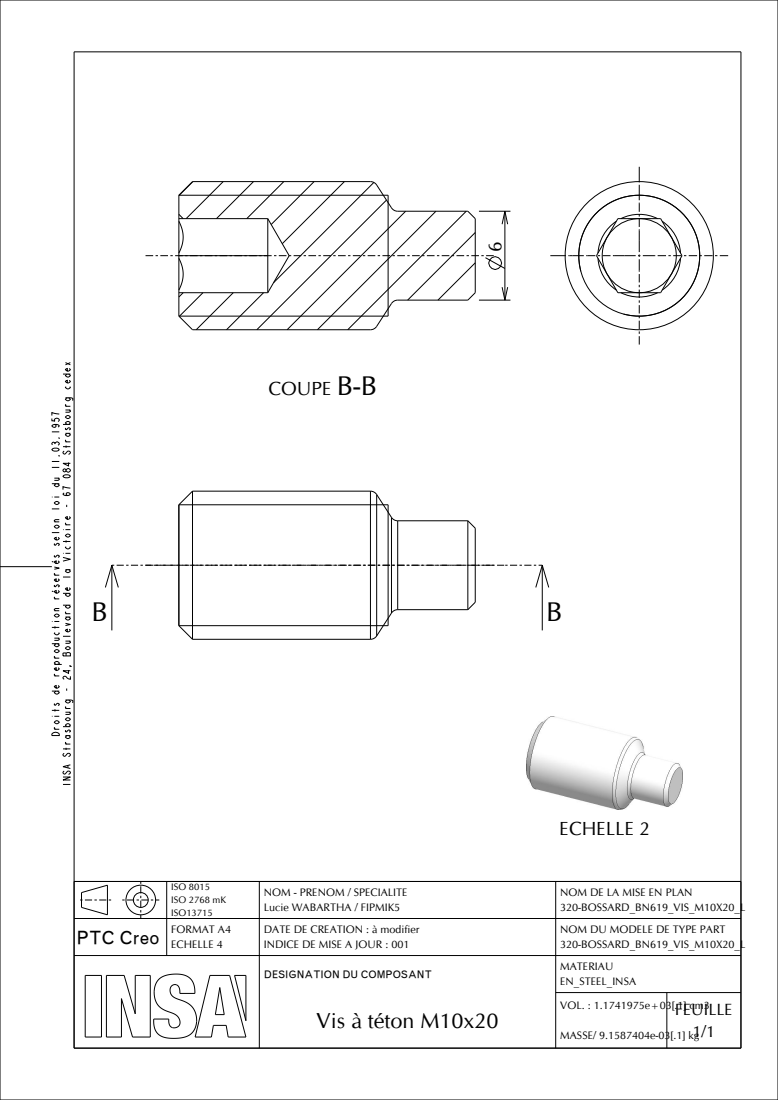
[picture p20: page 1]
COUPE B-B; ECHELLE 2

INSA Strasbourg - 24, Boulevard de la Victoire - 67 084 Strasbourg cedex

Droits de reproduction réservés selon loi du 11.03.1957

ISO 8015 ISO 2768 mK ISO13715 | NOM - PRENOM / SPECIALITE Lucie WABARTHA / FIPMIK5 | NOM DE LA MISE EN PLAN 320-BOSSARD_BN619_VIS_M10X20_L

PTC Creo | | FORMAT A4 ECHELLE 4 | DATE DE CREATION : à modifier INDICE DE MISE A JOUR : 001 | NOM DU MODELE DE TYPE PART 320-BOSSARD_BN619_VIS_M10X20_L

DESIGNATION DU COMPOSANT Vis à téton M10x20 | MATERIAU EN_STEEL_INSA

VOL. : 1.1741975e+03[.1] cm3 MASSE/ 9.1587404e-03[.1] kg | FEUILLE 1/1

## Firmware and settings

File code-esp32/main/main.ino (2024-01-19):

// V = voyant; BP = bouton poussoir; S = sélecteur; FC = fin de course; CS = chip select; ES = entrée/sortie; TEMP = température

// Alimentation ? https://docs.ai-thinker.com/_media/nodemcu32-s_specification_v1.3.pdf p.13

#include "SPI.h"
#include "WiFi.h"
#include "PubSubClient.h" 
#include "MCP23S17.h" // Rob Tillaart
#include "CytronMotorDriver.h"
#include <Adafruit_MAX31865.h>

// Définition des pins d'entrées/sorties
const uint8_t MOTEUR_A_FC_BAS         = 13;
const uint8_t MOTEUR_A_FC_HAUT        = 12;
const uint8_t MOTEUR_B_FC_BAS         = 14;
const uint8_t MOTEUR_B_FC_HAUT        = 27;
const uint8_t MOTEUR_A_DIRECTION_PIN  = 25;  // 0 = Sens positif; 1 = Sens négatif (mode automatique)
const uint8_t MOTEUR_A_VITESSE_PIN    = 26;  // 0 = Arrêt; 1 = Vitesse max (mode automatique); PWM
const uint8_t MOTEUR_B_DIRECTION_PIN  = 32;  // 0 = Sens positif; 1 = Sens négatif (mode automatique)
const uint8_t MOTEUR_B_VITESSE_PIN    = 33;  // 0 = Arrêt; 1 = Vitesse max (mode automatique); PWM
const uint8_t CAPTEUR_HUMIDITE_A_PIN  = 35;
const uint8_t CAPTEUR_HUMIDITE_B_PIN  = 34;

// CHIP SELECT pour la communication SPI
const uint8_t  MODULE_ES_CS     = 4;  // Module d'entrées/sorties MCP23S17
const uint8_t  MODULE_TEMP_A_CS = 2;  // Amplificateur de sonde de température PT100 MAX31865
const uint8_t  MODULE_TEMP_B_CS = 15; // Amplificateur de sonde de température PT100 MAX31865

// 0 = arrêt de sécurité; 1 = initialisation; 2 = marche normale; 3 = mode dégradé 
#define ARRET_SECURITE  0
#define INITIALISATION  1
#define MARCHE_NORMALE  2
#define MODE_DEGRADE    3

#define MARCHE_LENTE    127
#define MARCHE_RAPIDE   255
#define ARRET      0
#define MONTER     1
#define DESCENDRE -1

#define ENTREES 0
#define SORTIES 1

// La valeur de la résistance Rref. Utiliser 430.0 pour PT100 et 4300.0 pour PT1000
#define RREF 430.0

// La valeur 'nominale' de resistance de la sonde pour 0°C
// 100.0 pour PT100, 1000.0 pour PT1000
#define RNOMINAL 100.0

Adafruit_MAX31865 _thermoA = Adafruit_MAX31865(MODULE_TEMP_A_CS);
Adafruit_MAX31865 _thermoB = Adafruit_MAX31865(MODULE_TEMP_B_CS);

MCP23S17 _MODULE_ES(MODULE_ES_CS);

CytronMD _moteurA(PWM_DIR, MOTEUR_A_VITESSE_PIN, MOTEUR_A_DIRECTION_PIN);
CytronMD _moteurB(PWM_DIR, MOTEUR_B_VITESSE_PIN, MOTEUR_B_DIRECTION_PIN);

// WiFi 
const char *_ssid = "Alban";          // Entrez votre SSID WiFi  
const char *_motDePasse = "11111110"; // Entrez votre mot de passe WiFi 

// MQTT Broker  
const char *_mqttBroker = "172.20.10.4"; 
const char *_topic = "";  
const int _mqttPort = 1883; 

WiFiClient _espClient; 
PubSubClient client(_espClient);

uint8_t _etatMachine; // 0 = arrêt de sécurité; 1 = marche normale; 2 = mode dégradé; 3 = initialisation
bool _erreur;
unsigned long _deltaTempsMesure;
unsigned long _timeoutMoteurs;

// Variables globales
uint8_t module_ES_Entrees, module_ES_Sorties;
bool aeration_Mode_S, ventilation_Mode_S;
bool moteurA_Monter_BP, moteurA_Descendre_BP, moteurB_Monter_BP, moteurB_Descendre_BP;
bool moteurA_FC_Haut, moteurA_FC_Bas, moteurB_FC_Haut, moteurB_FC_Bas;
bool ventilation_MarcheArret_S;
bool acquittement_BP;

bool acquitter;
bool ventilation_Etat; // 0 = Arrêt, 1 = Marche
uint8_t moteurA_Etat; // 0 = Arrêt; 1 = Monter; 2 = Descendre
uint8_t moteurB_Etat; // 0 = Arrêt; 1 = Monter; 2 = Descendre

bool etatOrigineMoteur; // 0 = l'origine moteur n'a pas encore été effectuée; 1 = origine effectuée

unsigned long duree_MoteurA_Marche;
unsigned long duree_MoteurB_Marche;
unsigned long temps_actuel_Moteurs;

void definitionEntreesSorties() {
  // par défaut les modes des pins sont des entrées (INPUT)
  pinMode(MOTEUR_A_DIRECTION_PIN, OUTPUT);
  pinMode(MOTEUR_B_DIRECTION_PIN, OUTPUT);
  pinMode(MOTEUR_A_VITESSE_PIN, OUTPUT);
  pinMode(MOTEUR_B_VITESSE_PIN, OUTPUT);

  pinMode(MOTEUR_A_FC_BAS, INPUT);
  pinMode(MOTEUR_A_FC_HAUT, INPUT);
  pinMode(MOTEUR_B_FC_BAS, INPUT);
  pinMode(MOTEUR_B_FC_HAUT, INPUT);
}

void initialisationVariables() {
  module_ES_Entrees = 0x00;
  module_ES_Sorties = 0x00;
  etatOrigineMoteur = false;
  _timeoutMoteurs = 2 * 60 * 1000; // temps maximal d'allumage d'un moteur en millisecondes
}

// Connexion au réseau WiFi
// TODO : Ajouter une limite de temps
void connexionWiFi() {
  WiFi.begin(_ssid, _motDePasse);
  while (WiFi.status() != WL_CONNECTED) { 
    delay(500); 
    Serial.println("Connecting to WiFi..");
  }
}

// Connexion au réseau MQTT
// TODO : Ajouter une limite de temps
void connexionMQTT() {
  client.setServer(_mqttBroker, _mqttPort); 
  client.setCallback(callback); 
  while (!client.connected()) { 
    delay(500); 
    Serial.println("Connecting to MQTT..");
  }
}

// TODO : Ajouter alerte si limite de temps dépassée + gestion des erreurs
bool origineMoteurs() {
  Serial.print("Origine Moteurs : MoteurA ");
  if (!digitalRead(MOTEUR_A_FC_BAS)){_moteurA.setSpeed(MARCHE_RAPIDE * DESCENDRE);}
  while (!digitalRead(MOTEUR_A_FC_BAS)){delay(500);}
  _moteurA.setSpeed(ARRET);
  Serial.print("MoteurB ");
  if (!digitalRead(MOTEUR_B_FC_BAS)){_moteurB.setSpeed(MARCHE_RAPIDE * DESCENDRE);}
  while (!digitalRead(MOTEUR_B_FC_BAS)){delay(500);}
  _moteurB.setSpeed(ARRET);
  etatOrigineMoteur = true;
  Serial.println("OK");
  return true; // true si pas d'erreur, sinon false
}

 // Reception du message MQTT 
void callback(char *topic, byte *payload, unsigned int length) { 
  Serial.println("Callback MQTT");

}

// Retourne la valeur moyenne en %RH de l'humidité de la serre
float acquisitionHumidite() {
  Serial.print("Acquisition Humidité : ");
  uint16_t humiditeA = 0;
  uint16_t humiditeB = 0;
  uint16_t humidite = 0;
  uint8_t echantillonage = 3;
  for (uint8_t i = 0; i < echantillonage; i++) {
    humiditeA += analogReadMilliVolts(CAPTEUR_HUMIDITE_A_PIN);
    //humiditeB += analogReadMilliVolts(CAPTEUR_HUMIDITE_B_PIN);
    delay(2000);
  }
  humiditeB = humiditeA;
  humidite = (0.03892*0.5*(humiditeA+humiditeB)/echantillonage) - 42.017;
  Serial.println(humidite);
  return humidite;
}

// Retourne la valeur moyenne en °C de la température de la serre
float acquisitionTemperature() {
  Serial.print("Acquisition Température : ");
  uint16_t temperatureA = 0;
  uint16_t temperatureB = 0;
  uint16_t temperature = 0;
  uint8_t echantillonage = 3;
  for (uint8_t i = 0; i < echantillonage; i++) {
    temperatureA += _thermoA.temperature(RNOMINAL, RREF);
    //temperatureB += _thermoB.temperature(RNOMINAL, RREF);
    delay(2000);
  }
  temperatureB = temperatureA;
  temperature = 0.5 * (temperatureA + temperatureB) / echantillonage;
  Serial.println(temperature);
  return temperature;
}

void lireEntrees() {
  Serial.print("---LECTURE DES ENTREES---");
  moteurA_FC_Haut   = digitalRead(MOTEUR_A_FC_HAUT);
  moteurA_FC_Bas    = digitalRead(MOTEUR_A_FC_BAS);
  moteurB_FC_Haut   = digitalRead(MOTEUR_B_FC_HAUT);
  moteurB_FC_Bas    = digitalRead(MOTEUR_B_FC_BAS);

  // Déclaration des variables pour chaque entrée
  bool entrees[8];
  module_ES_Entrees = _MODULE_ES.read8(ENTREES);

  // Boucle pour extraire et inverser chaque bit d'entrée
  for (int i = 0; i < 8; i++) {
    entrees[i] = (module_ES_Entrees & (1 << i)) >> i;
    Serial.print(entrees[i]);
  }
  Serial.println();
  // Attribution des variables aux entrées spécifiques
  ventilation_MarcheArret_S = entrees[0];
  ventilation_Mode_S = entrees[1];
  moteurB_Descendre_BP = entrees[2];
  moteurB_Monter_BP = entrees[3];
  moteurA_Descendre_BP = entrees[4];
  moteurA_Monter_BP = entrees[5];
  aeration_Mode_S = entrees[6];
  acquittement_BP = entrees[7];
  }

void ecrireSorties() {
  Serial.print("---ECRITURE DES SORTIES--- : \nVentilation et Voyants :");
  // 7 = Marche/Arrêt Ventilation; 4 = Voyant Ventilation; 3 = Voyant moteur B; 2 = Voyant moteur A; 1 = Voyant erreur; 0 = Voyant acquitement
  module_ES_Sorties = ((ventilation_Etat << 7) | (0 << 6) | (0 << 5) | (ventilation_Etat << 4) | (((moteurB_Etat>0)?1:0) << 3) | (((moteurA_Etat>0)?1:0) << 2) | (_erreur << 1) | acquitter);
  _MODULE_ES.write8(SORTIES, module_ES_Sorties);
  Serial.println(module_ES_Sorties);
  Serial.print("Moteurs :");
  Serial.printf("A:%d B%d", moteurA_Etat, moteurB_Etat);

  switch(moteurA_Etat) {
    case 0:
      _moteurA.setSpeed(MARCHE_LENTE * ARRET);
      duree_MoteurA_Marche = 0;
      temps_actuel_Moteurs = millis();
      break;
    case 1:
      _moteurA.setSpeed(MARCHE_LENTE * MONTER);
      duree_MoteurA_Marche = millis() - temps_actuel_Moteurs;
      break;
    case 2:
      _moteurA.setSpeed(MARCHE_LENTE * DESCENDRE);
      duree_MoteurA_Marche = millis() - temps_actuel_Moteurs;
      break;
    default:
      _moteurA.setSpeed(MARCHE_LENTE * ARRET);
      duree_MoteurA_Marche = 0;
      temps_actuel_Moteurs = millis();
      break;
  }
      
  switch(moteurB_Etat) {
    case 0:
      _moteurB.setSpeed(MARCHE_LENTE * ARRET);
      break;
    case 1:
      _moteurB.setSpeed(MARCHE_LENTE * MONTER);
      break;
    case 2:
      _moteurB.setSpeed(MARCHE_LENTE * DESCENDRE);
      break;
    default:
      _moteurB.setSpeed(MARCHE_LENTE * ARRET);
      break;
  }
  /*
  if (duree_MoteurA_Marche >= timeoutMoteurs) {
    _erreur = true;
    // Serial.println("Timeout Moteur A");
  } 
  */
}

void modeManuel() {
  Serial.println("---MODE MANUEL---");
  if (moteurA_Monter_BP && !moteurA_FC_Haut && !_erreur) {
      moteurA_Etat = 1;
      } else if (moteurA_Descendre_BP && !moteurA_FC_Bas && !_erreur) {
        moteurA_Etat = 2;
        } else {moteurA_Etat = 0;}
  if (moteurB_Monter_BP && !moteurB_FC_Haut && !_erreur) {
    moteurB_Etat = 1;
    } else if (moteurB_Descendre_BP && !moteurB_FC_Bas && !_erreur) {
      moteurB_Etat = 2;
      } else {moteurB_Etat = 0;}
  if (ventilation_MarcheArret_S && !_erreur) {
    ventilation_Etat = 1;
    } else {ventilation_Etat = 0;}
}

void modeAutomatique() {
  Serial.println("---MODE AUTOMATIQUE---");
  delay(100);

}

void setup() {
  // temporisation pour que tous les composants soit bien allumés
  delay(5000);
  Serial.begin(115200);
  Serial.println("--INITIALISATION--");

  initialisationVariables();

  // Communication SPI
  SPI.begin();

  definitionEntreesSorties();
  
  _thermoA.begin(MAX31865_3WIRE);  // mettre 2WIRE ou 4WIRE en fonction du besoin
  //_thermoB.begin(MAX31865_3WIRE);  // mettre 2WIRE ou 4WIRE en fonction du besoin

  // Configuration du module d'entrées/sorties
  _MODULE_ES.begin();
  _MODULE_ES.pinMode8(ENTREES, 0xFF);      //  0x00 = output , 0xFF = input
  _MODULE_ES.pinMode8(SORTIES, 0x00);
  _MODULE_ES.setPolarity8(0, 0xFF);  // 0 = NC, 1 = NO
  
  //connexionWiFi();
  //connexionMQTT();
  origineMoteurs();
}

void loop() {
  // Vérifier la connexion au réseau WiFi
  //if (WiFi.status() != WL_CONNECTED) {connexionWiFi();}

  // Vérifier la connexion au broker MQTT
  //if (!client.connected()) {connexionMQTT();}

  if (!etatOrigineMoteur){origineMoteurs();}

  // Lecture des entrées
  lireEntrees();

  // Acquisition de la donnée

  // Récupérer les données du serveur via MQTT


  // Traitement des données

  // Mode manuel
  if (!aeration_Mode_S) {
    modeManuel();
  }
  
  // Mode automatique
  if (aeration_Mode_S) {
    modeAutomatique();
  }

  // Envoyer les données au serveur via MQTT  
  
  // Ecriture des sorties
  ecrireSorties();  

  //delay(500);
}

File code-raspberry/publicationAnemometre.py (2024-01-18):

from gpiozero import MCP3008
import paho.mqtt.client as mqtt
import datetime
import json
from time import sleep
import parametres as param
import random

##############################################################################################################################
#### Ce fichier python permet de publier les valeurs de l'anemomètre placé sur la serre
#### Version 1.0 du 07/01/2024
##############################################################################################################################



#==========SETUP ADC==========#
# creation d'un objet channel 0 de l'objet ADC MCP3008 
# un channel est une entrée analogique, le MCP3008 peut en avoir jusqu'à 8

channel_anemometre = MCP3008(0) # a activer en version finale

#==========SETUP VALUES==========#

valeurAleatoire = 20.0 # pour les tests
maxVent = 0
temporisationEnvoi = 5 #temps entre deux publications de vent
temporisationReleves = 20

#==========SETUP MQTT==========#

def on_connect(client, userdata,flags, rc):
    if rc==0:
        print("Connected to MQTT Broker! Returned code: "+str(rc))
    else:
        print("Failed to connect. Returned code: "+str(rc))

def on_message(client, userdata, msg):
    topic=msg.topic
    message_decode=str(msg.payload.decode("utf-8","ignore"))
    #si c'est une nouvelle valeur setup alors on l'enregistre en local
    if topic == param.topicGrangeAnemoParamRep:
        message_in=json.loads(message_decode)
        maxVent = message_in["valeurMax"]
        print("nouvelle valeur max : " + str(maxVent))
    #sinon on ne fait rien
    
def on_disconnect(client, userdata, rc):
    print("Client Got Disconnected")
    if rc != 0: 
        print("Unexpected MQTT disconnection. Will auto-reconnect")
    
def  recupererValeursSetup():
    pass

mqtt_client = mqtt.Client()
mqtt_client.on_connect = on_connect
mqtt_client.on_message = on_message
mqtt_client.connect(param.IP_ADRESS, param.PORT)
mqtt_client.loop_start()
mqtt_client.subscribe(param.topicGrangeAnemoDonnees)
mqtt_client.subscribe(param.topicGrangeAnemoParamRep)

#==========RELEVE DU VENT==========#

def releveVent(temporisationReleves) -> float:
    nbValeurs = 3
    sommeValeurs = 0.0
    # ajouter un try catch
    for valeur in nbValeurs:
        valeur = 6*channel_anemometre.value # relevé
        sommeValeurs = sommeValeurs + valeur
        sleep(temporisationReleves)
    valeurMoyenne = sommeValeurs/nbValeurs
    return valeurMoyenne
    
#==========MAIN==========#

# envoie d'un get value
# récupération de la valeur (qui est udate si nouveau message durant le fonctionnement)
mqtt_client.publish(param.topicGrangeAnemoParamReq, "SETUP")

while True:

    valeurVent = releveVent(temporisationReleves) #valable pour l'anemometre final
    
    # valeurVent= random.randrange (valeurAleatoire-3,valeurAleatoire+3,1)
    # if valeurVent <0:
    #     valeurVent = 0
    # elif valeurVent>100:
    #     valeurVent = 100
    
    #valeurAleatoire= valeurVent
    dictionnaireMessage = {"lieu":"grange","categorie":"anemometre","valeur": valeurVent ,"date":str(datetime.datetime.now())}
    #exemple de reglage :     dictionnaireParametres = {"groupe":"grange","capteur": "anemometre","valeurMin": 0.0 , "valeurMax": 20.0 ,"date":str(datetime.datetime.now())}

    jsonMessage = json.dumps(dictionnaireMessage)

    mqtt_client.publish(param.topicGrangeAnemoDonnees,jsonMessage)
    sleep(temporisationEnvoi)

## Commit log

2023-11-16 Add directories and code example for esp32
2023-12-01 declaration des cstes et variable, setup()
2023-12-13 code raspberry : ajout de l'enregistrementDB, du fichier parametres, de publicationAnemometre et de l'app streamlit
2023-12-18 ajout de db_sensors et de loiCommande
2024-01-07 refonte des fichiers de base + comm anemometre ok
2024-01-08 ajout des onglets profils et consignes de serre
2024-01-16 modification enregistrementdb: simplification de la creation et enregistrement
2024-01-18 test des moteurs dans main
2024-01-19 refactoring et organisation modes esp32
2024-02-02 dessin 3D accouplement moteur
    [accouplement.stp, arbre_reducteur.stp, entree_bras_telesc.stp]
2024-02-04 modèles CAO accouplement moteur
    [10-accouplement.dxf, 10-accouplement.prt, 10-accouplement.stp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]
2024-02-05 Ajout des originaux CdC et FdP
    [Feuille_demarrage_projet.xlsx]
2024-02-06 dossier accouplement moteur dans CAO
    [10-accouplement.dxf, 10-accouplement.prt, 10-accouplement.stp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]
